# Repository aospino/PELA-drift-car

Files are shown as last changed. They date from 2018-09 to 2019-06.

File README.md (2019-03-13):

# PELA Drift Car
## 3D Printed LEGO-compatible 1:10 Scale RC Drift Car Cover

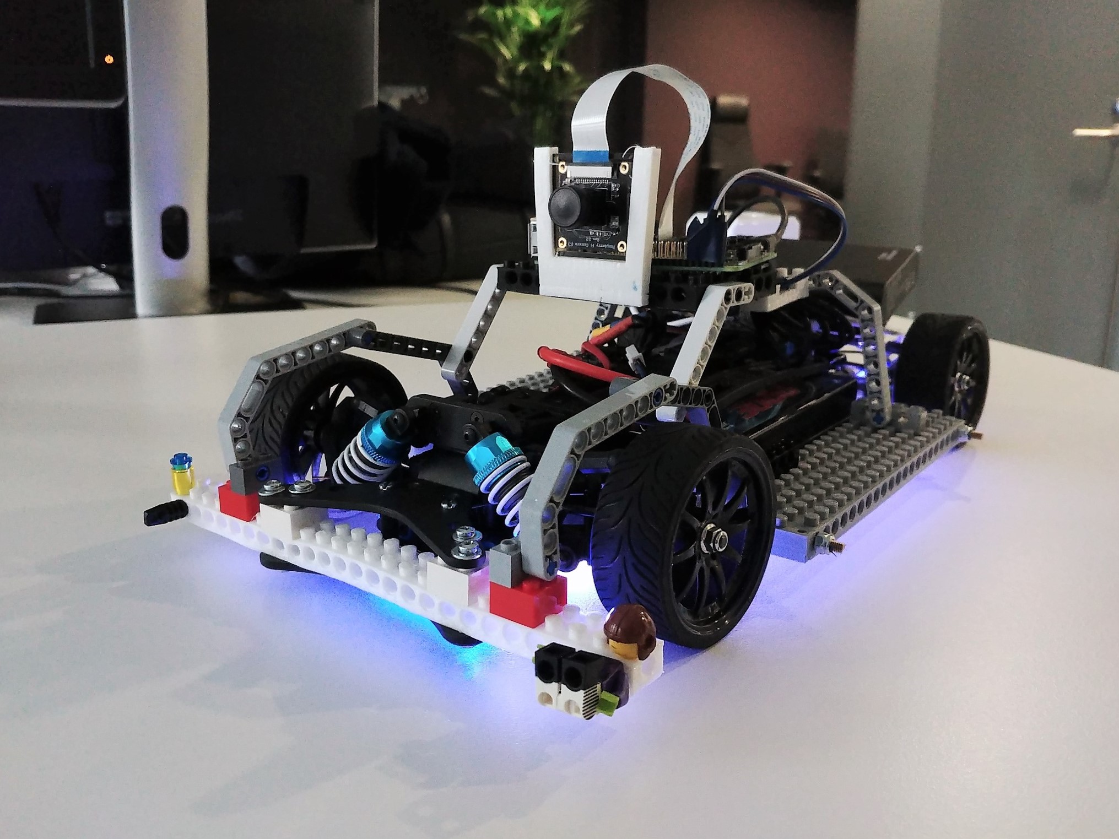
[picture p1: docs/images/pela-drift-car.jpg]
PELA Drift Car


`git clone git@github.com:LEGO-compatible-gadgets/PELA-drift-car.git --recurse-submodules`

Please visit the [GitHub Documentation](https://github.com/LEGO-compatible-gadgets/PELA-drift-car/tree/master/docs/README.md) for more information

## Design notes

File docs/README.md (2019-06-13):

# PELA Autonomous Drift Car
## 3D Printed LEGO-compatible Parametric 1:10 Scale RC Drift Car Cover Based On [PELA Blocks](http://pelablocks.org)

A high-end RC drift car is modified with 3D printed PELA blocks, LEGO technics, a Raspberry Pi 3+ and camera to drive itself. Snap on additional sensors and custom body parts as your design evolves. At Futurice, we use this to compete and learn. Our different offices race each other to see who has the mad deep learning skills to drive the car around a track the fastest.

To install, get the last preview release of [OpenSCAD](https://www.openscad.org/) then:

`git clone git@github.com:LEGO-compatible-gadgets/PELA-drift-car.git --recurse-submodules`

PELA Carson Drift Car

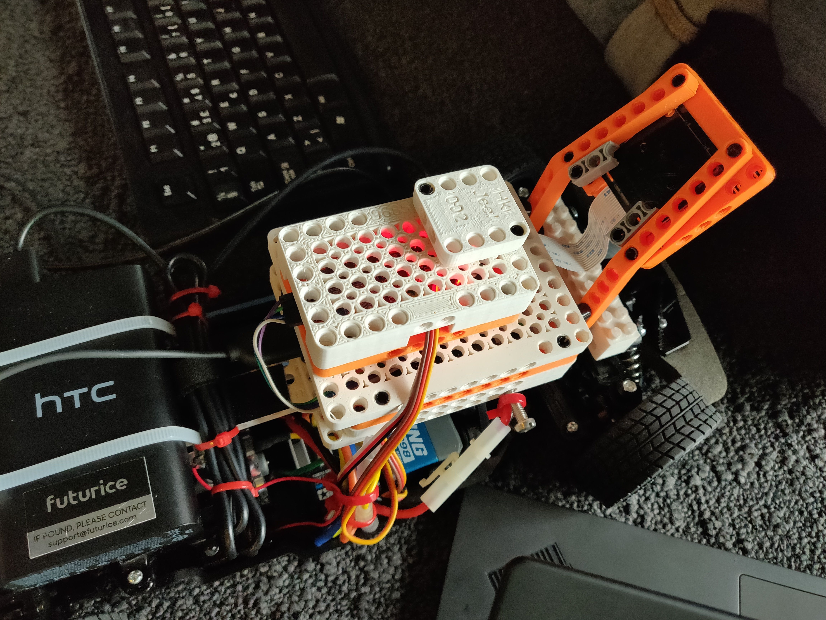
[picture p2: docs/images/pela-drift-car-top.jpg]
PELA TT-02 Drift Car


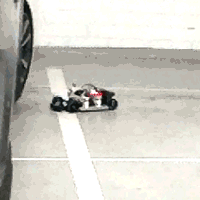
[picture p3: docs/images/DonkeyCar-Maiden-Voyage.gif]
PELA Drift Car Maiden Voyage




**This drift car is a work in progress.** PELA Blocks and some imagination with LEGO technics will offer you all the parts you need and see here in the picture. Instructions are currently a bit thin as we iterate fast. We'll get to it. Promise.

This car has been designed to compete in [Markku.ai](https://markku.ai/). You can find more resources and ideas there. **Markku.ai** is a **Donkeycar**-derived autonomous driving competition based using high end 1:10 electric drift cars. If you're going to crah- do it with style.

Please see [donkeycar.com](http://www.donkeycar.com/) for help with the basic software setup. This car is a high performace, pimped-out version of what you find there.

## Assembly Instructions

PELA Drift Car Assembly

[PELA Drift Car Assembly](https://github.com/LEGO-compatible-gadgets/PELA-drift-car/blob/master/PELA-drift-car-assembly.stl) Calibrate for your pinter as described in [PELA Blocks](https://pelablocks.org) and then export the calibrated models from [OpenSCAD](https://www.openscad.org/). Purchase a TT-02 car, boards, power bank battery and a bag of technic pins as needed. Aseemble according to the image and linked websites above. Drive. Win. 

## Models

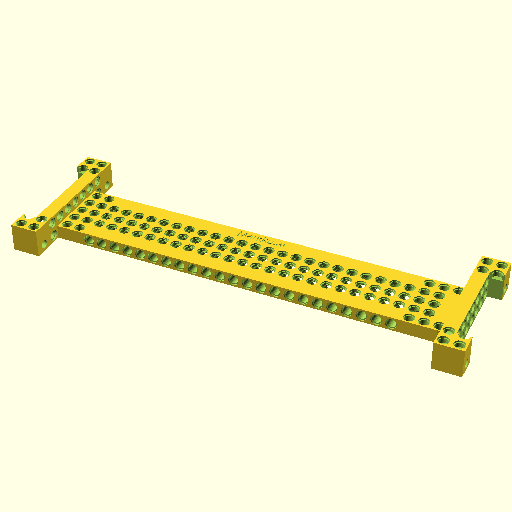
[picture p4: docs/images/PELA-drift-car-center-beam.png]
PELA Drift Car Center Beam


[PELA Drift Car Center Beam](https://github.com/LEGO-compatible-gadgets/PELA-drift-car/blob/master/PELA-drift-car-center-beam.stl) A configurable spine that runs down the center of an RC car for attaching other PELA parts. This part makes future upgrades and field reconfiguration and repair easier and much faster by using only technic pins are needed to make changes. For smaller printers, you may optionally render this as two shorter sections that can be joined by placing technic beams down the sides ovelapping both pieces. Use what you have laying around or print from [PELA technic beam](https://pelablocks.org).

___

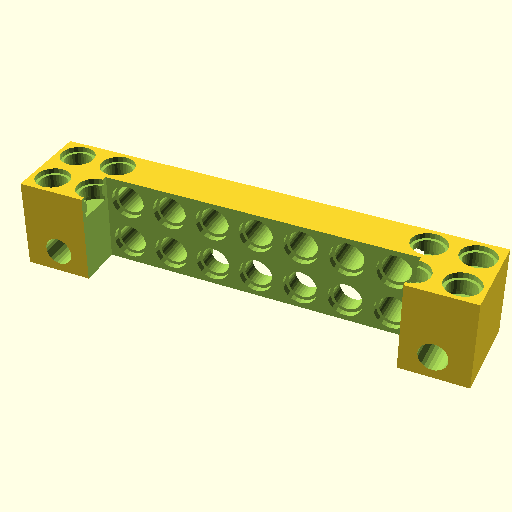
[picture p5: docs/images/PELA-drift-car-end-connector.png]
PELA Drift Car End Connector


[PELA Drift Car End Connector](https://github.com/LEGO-compatible-gadgets/PELA-drift-car/blob/master/PELA-drift-car-end-connector.stl) An adapter for both ends of the Drift Car Center Beam. Two mounting holes at each end allow quick disconnect of the entire electronics beam from the donor Tamiya TT-02 1:10 RC drift car. From the drop-down menu in OpenSCAD you can select an alternative design for a Carson drift car. The end connector holes line up with each car's mount holes. Use long technic pins or bolts to mount the end connector to the car near the suspension. The TT-02 model can be used for both front and back. The Carson connector only fits at the back of the car, so use a [strap mount](https://github.com/LEGO-compatible-gadgets/PELA-parametric-blocks/blob/master/PELA-strap-mount.stl) of appropriate size for the front attachment.

___

PELA Drift Car Tamiya TT-02 Body Mount

[PELA Drift Car Tamiya TT-02 Body Mount](https://github.com/LEGO-compatible-gadgets/PELA-drift-car/blob/master/PELA-body-mount.stl) An optional mounting point for a pre-made polycarbonate car body shell.

___

PELA Raspberry Pi 3B Technic Mount

[PELA Raspberry Pi 3B Technic Mount](https://github.com/LEGO-compatible-gadgets/PELA-parametric-blocks/blob/master/technic-mount/PELA-raspberry-pi3-technic-mount.stl) A Raspberry Pi 3B+ holder.

___

PELA PCA9685 16 Channel Servo Board Technic Mount

[PELA PCA9685 16 Channel Servo Board Technic Mount](https://github.com/LEGO-compatible-gadgets/PELA-parametric-blocks/blob/master/technic-mount/PELA-pca9685-servo-board-technic-mount.stl) For holding a servo driver board to the center bar.

___

PELA Raspberry Pi Camera Technic Mount

[PELA Raspberry Pi Camera Technic Mount](https://github.com/LEGO-compatible-gadgets/PELA-parametric-blocks/blob/master/technic-mount/PELA-raspberry-pi-camera-technic-mount.stl) A Raspberry Pi 3 camera holder.

___

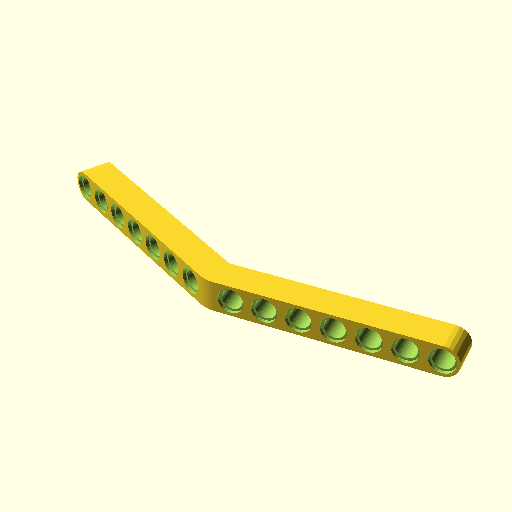
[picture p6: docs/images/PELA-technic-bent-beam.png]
PELA Technic Bent Beam


[PELA Technic Bent Beam](https://github.com/LEGO-compatible-gadgets/PELA-drift-car/blob/master/PELA-technic-bent-beam.stl) This is to mount the front wide angle Pi camera to the front TT-02 End Connector at a 30 degree down angle. Print two copies and make two small holes in the shell.

___

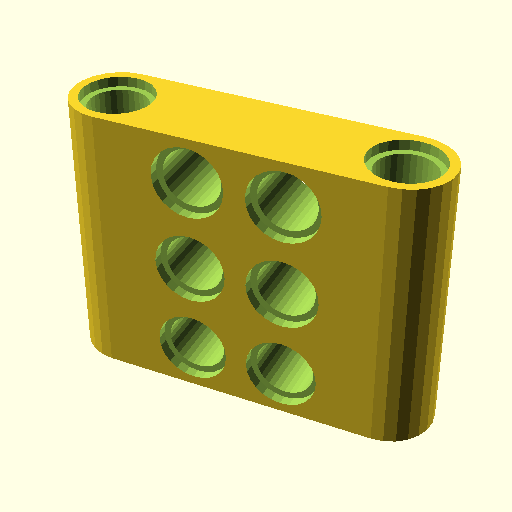
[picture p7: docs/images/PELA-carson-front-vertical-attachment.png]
PELA Vertical Attachment


[PELA Vertical Attachment](https://github.com/LEGO-compatible-gadgets/PELA-drift-car/blob/master/PELA-carson-front-vertical-attachment.stl) Two copies of this stick down from the front part of the center beam on a Carson to help with wire tie attachment to the center beam of the car.

___

PELA Technic Sign

[PELA Technic Sign](https://github.com/LEGO-compatible-gadgets/PELA-parametric-blocks/blob/master/sign/PELA-technic-sign.stl) A sign you can use to name and label your model.

## Downloading

If you prefer to avoid git, you can download the files instead.

1. Download and unzip **[PELA Drift Car](https://github.com/LEGO-Prototypes/PELA-drift-car/archive/master.zip)**
1. Download and unzip **[PELA Blocks](https://github.com/LEGO-Prototypes/PELA-blocks/archive/master.zip)** as a subdirectory inside the above (`PELA-robot-hand/PELA-blocks`)
1. **Calibrate** the models to your printer/filament/slicer/preferences (see below)

## Git Clone

1. `git clone git@github.com:LEGO-compatible-gadgets/PELA-drift-car.git --recurse-submodules`
1. **Calibrate** the models to your printer/filament/slicer/preferences (see below)
1. Before `git submodule update --remote` to get PELA Blocks project changes, you may want to [backup your print calibration files](http://pelablocks.org/#calibration-file-backup)

## Calibration

**IMPORTANT:** The STL models must be customized for your material, printer and slicer. First **[calibrate](http://pelablocks.org/#calibrate)** the PELA blocks for your printer to achieve a nice snap fit.

See also [Advanced Calibration](http://pelablocks.org/ADVANCED-CALIBRATION)

## Calibration File Backup

If you later update the PELA-blocks project to a newer version, you risk overwirting and loosing your calibration customizations. The simplest solution is to create a backup copy those settings.

1. `cd PELA-drift-car/PELA-Blocks`
1. `cp PELA-parameters.scad ../PELA-parameters-backup.scad`
1. `cp PELA-print-parameters.scad ../PELA-print-parameters-backup.scad`

## Use

Edit the [OpenSCAD](http://www.openscad.org/) files to generate different views such as one finger at a time.

Be patient, have a nice meal and a coffee, the models are complex and render slowly.

## License



**Creative Commons Attribution-ShareAlike 4.0 International License**

These designs are by PELA project contributors, not by the LEGO corporation. They are compatible with LEGO and similar blocks available from multiple manufacturers and online projects. The associated patents have expired. These designs are not identical to LEGO; they have been specially modified for easy 3D printing and offered in the spirit of open source collaborative innovation.

If what you want is available as injection molded plastic, buy it for the higher quality and durability. These model are helpful when you want something customized, a special color, an unusual material, and for replacement parts when you just can't wait.

## Open source design, Powered By Futurice

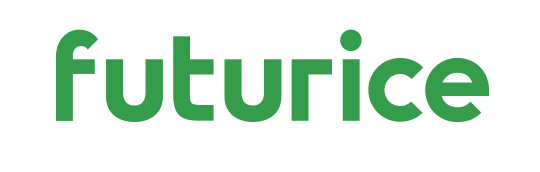
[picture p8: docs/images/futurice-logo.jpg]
Futurice (https://futurice.com)


These open source designs are brought to you by [Futurice](http://futurice.com) and contributions from the community. Come work with the best.

The software needed is free and open source, [OpenSCAD](http://www.openscad.org/). You can probably learn it in less than an hour.

## Contact

Collaboration and pull requests are welcome: [Git Project](https://github.com/LEGO-Prototypes/PELA-drift-car)

paul.houghton@futurice.com ( **[Blog](https://medium.com/@paulhoughton)** - **[Twitter](https://twitter.com/mobile_rat)** )

If you like it, please tweet about us! [](https://twitter.com/intent/tweet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)

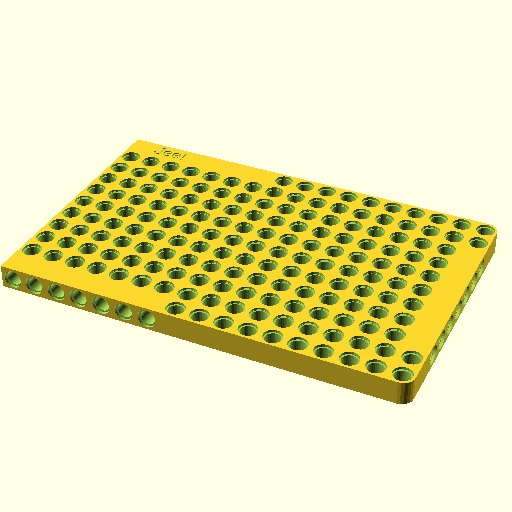
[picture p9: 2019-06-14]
docs/images/PELA-carson-center-beam.png

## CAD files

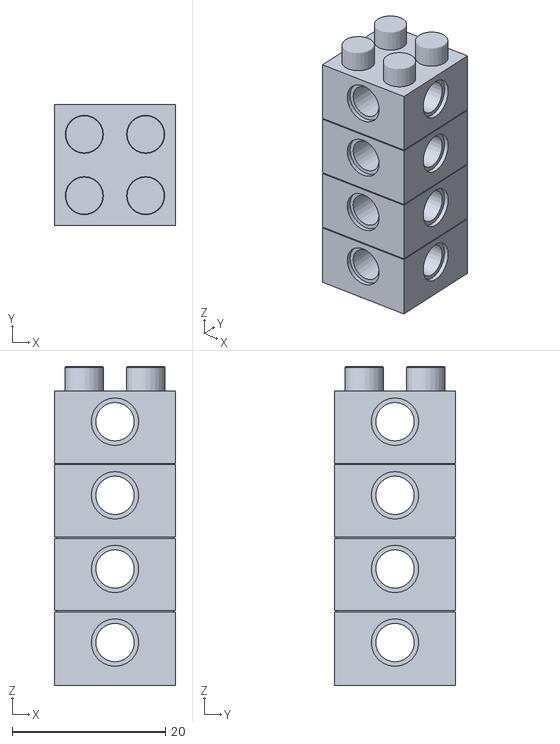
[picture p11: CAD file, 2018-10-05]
docs/riser-4-2-4.stl
15.8 x 15.8 x 41.6

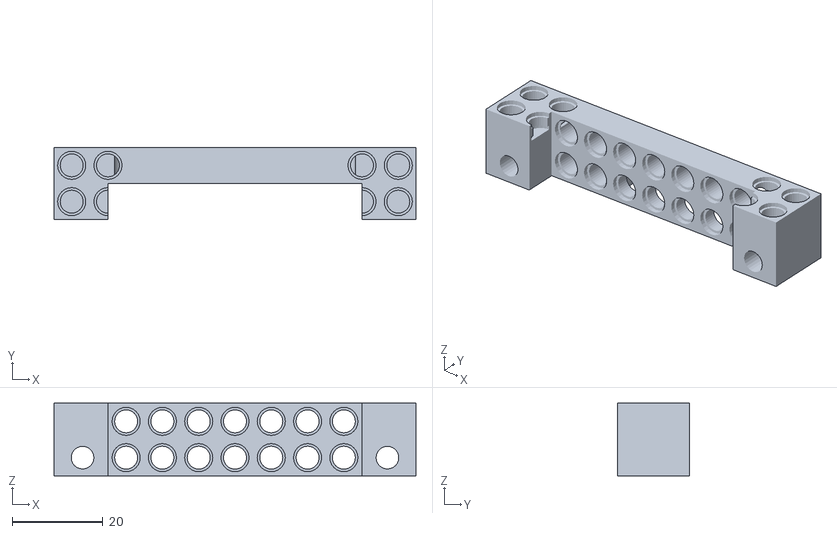
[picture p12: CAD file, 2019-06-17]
PELA-drift-car-end-connector.stl
79.8 x 15.8 x 16.0

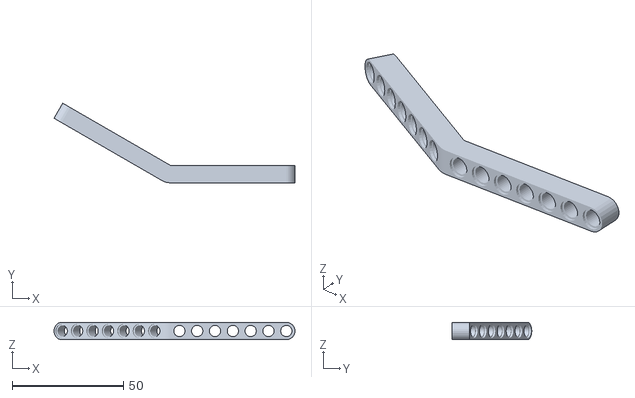
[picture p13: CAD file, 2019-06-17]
PELA-technic-bent-beam.stl
108.2 x 35.8 x 7.80

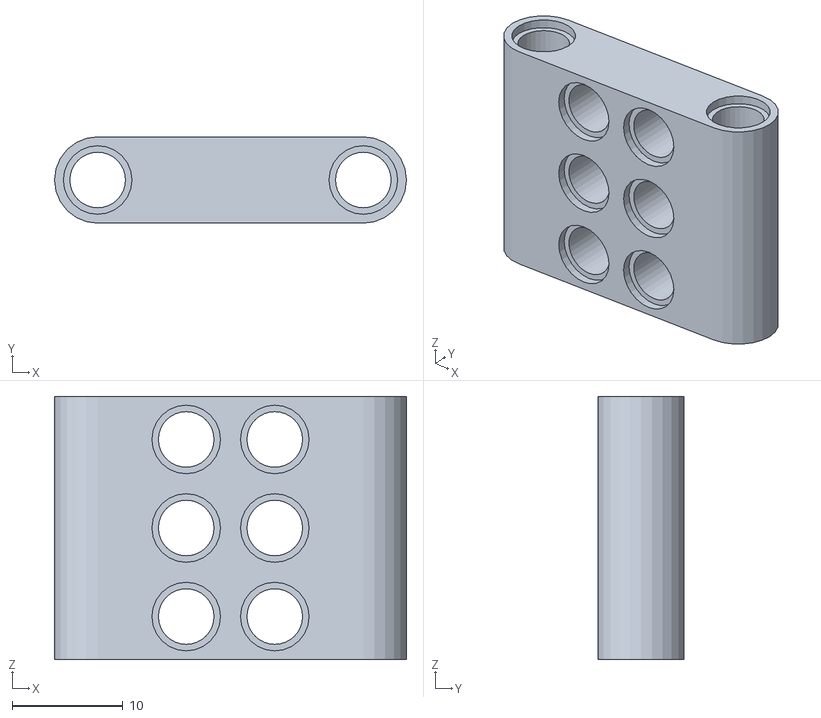
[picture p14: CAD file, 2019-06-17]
PELA-carson-front-vertical-attachment.stl
31.8 x 7.80 x 23.8

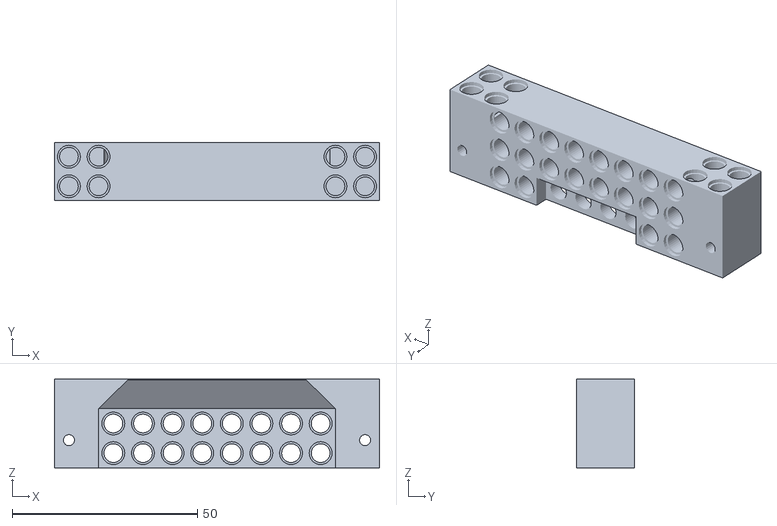
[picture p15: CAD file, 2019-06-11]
PELA-carson-drift-car-end-connector.stl
87.8 x 15.8 x 24.0

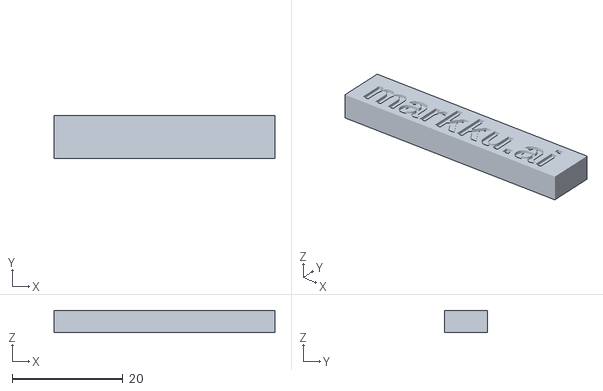
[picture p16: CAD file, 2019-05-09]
PELA-panel-sign.stl
39.8 x 7.82 x 4.00

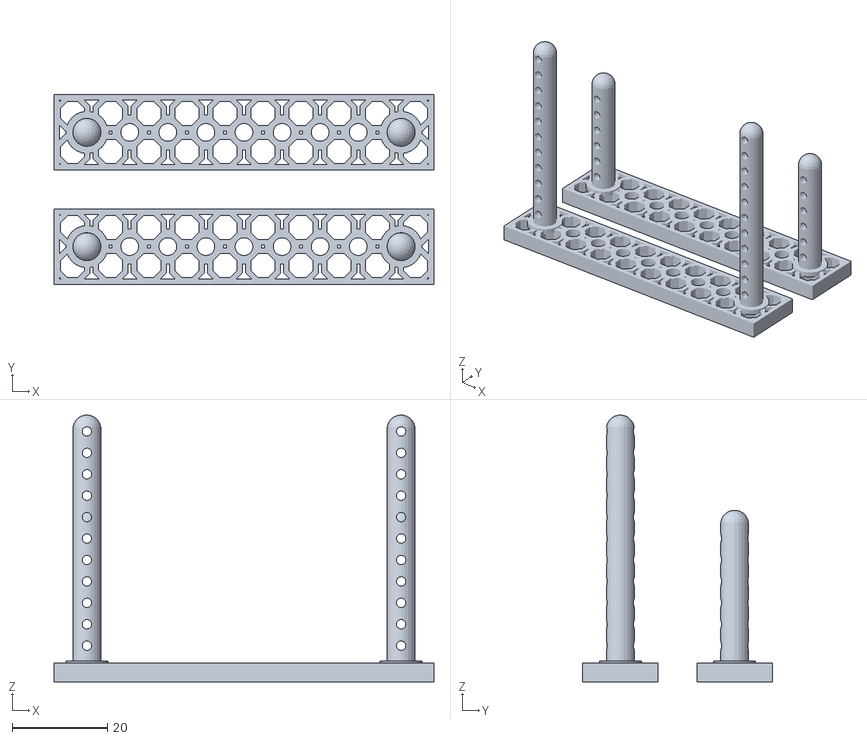
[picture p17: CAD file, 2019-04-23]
PELA-body-mount.stl
79.8 x 39.8 x 56.0

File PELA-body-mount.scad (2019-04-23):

/*
PELA Parametric Socket Panel Generator

Published at https://PELAblocks.org

By Paul Houghton
Twitter: @mobile_rat
Email: paulirotta@gmail.com
Blog: https://medium.com/@paulhoughton

Creative Commons Attribution-ShareAlike 4.0 International License
    https://creativecommons.org/licenses/by-sa/4.0/legalcode

Open source design, Powered By Futurice. Come work with the best.
    https://www.futurice.com/

Import this into other design files:
    use <PELA-block.scad>
*/

include <PELA-parametric-blocks/style.scad>
include <PELA-parametric-blocks/material.scad>
use <PELA-parametric-blocks/PELA-socket-panel.scad>



/* [Render] */

// Show the inside structure [mm]
cut_line = 0; // [0:1:100]

// Printing material (set to select calibrated knob, socket and axle hole fit)
material = 0; // [0:PLA, 1:ABS, 2:PET, 3:Biofila Silk, 4:Pro1, 5:NGEN, 6:NGEN FLEX, 7:Bridge Nylon, 8:TPU95, 9:TPU85/NinjaFlex]

// Is the printer nozzle >= 0.5mm? If so, some features are enlarged to make printing easier
large_nozzle = true;


/* [Body Mount] */

// Length of the socket panel [blocks]
l = 10; // [1:1:20]

// Width of the socket panel [blocks]
w = 4; // [1:1:20]

// Presence of sockets vs a plain panel
sockets = true;

// Add interior fill for the base layer
solid_first_layer = false;

// Basic unit vertical size of each block
block_height = 8; // [8:technic, 9.6:traditional blocks]


/* [Body Pins] */

// Space between the two front pin centers
pin_separation = 66.4; // [0:0.1:200]

// Thickness of the pin
pin_diameter = 5.8; // [0:0.1:20]

// Length of the pins
front_pin_height = 30.0; // [0:0.1:200]

// Length of the pins
back_pin_height = 50.0; // [0:0.1:200]

// Size of cotter pin holes in each pin
pin_hole_diameter = 2.0; // [0:0.1:20]

// Distance between cotter pin holes in each pin
pin_hole_spacing = 4.5; // [0:0.1:20]


///////////////////////////////
// DISPLAY
///////////////////////////////

front_body_mount();

translate([0, -block_width(w + 1), 0]) {
    back_body_mount();
}


module front_body_mount() {
    socket_panel(material=material, large_nozzle=large_nozzle, cut_line=cut_line, l=l, w=w, sockets=sockets, solid_first_layer=solid_first_layer, skin=skin, block_height=block_height);
    
    body_pin_set(pin_height=front_pin_height);
}

module back_body_mount() {
    socket_panel(material=material, large_nozzle=large_nozzle, cut_line=cut_line, l=l, w=w, sockets=sockets, solid_first_layer=solid_first_layer, skin=skin, block_height=block_height);
    
    body_pin_set(pin_height=back_pin_height);
}


module body_pin_set(pin_height = undef) {    
    translate([(block_width(l)-pin_separation)/2, 0, 0]) {
        body_pin(pin_height = pin_height);
    }
    
    translate([(block_width(l)+pin_separation)/2, 0, 0]) {
        body_pin(pin_height = pin_height);
    }
}

module body_pin(pin_height=undef) {
    assert(pin_height != undef);
    
    translate([0, block_width(w-1), knob_height+2*skin]) {
        difference() {
            union() {
                cylinder(d=pin_diameter, h=pin_height);
                translate([0, 0, pin_height]) {
                    sphere(d=pin_diameter);
                }
                cylinder(d=2*pin_diameter, h=panel_height());
            }

            for (i=[2*pin_hole_spacing:pin_hole_spacing:pin_height]) {
                translate([0, -pin_diameter, i]) {
                    rotate([-90, 0, 0]) {
                        cylinder(d=pin_hole_diameter, h=2*pin_diameter);
                    }
                }
            }
        }
    }
}

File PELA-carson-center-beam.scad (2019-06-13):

/*
PELA Slot Mount - 3D Printed LEGO-compatible PCB mount, vertical slide-in

Published at https://PELAblocks.org

By Paul Houghton
Twitter: @mobile_rat
Email: paulirotta@gmail.com
Blog: https://medium.com/@paulhoughton

Creative Commons Attribution ShareAlike NonCommercial License
    https://creativecommons.org/licenses/by-sa/4.0/legalcode

Design work kindly sponsored by
    https://www.futurice.com

All modules are setup for stateless functional-style reuse in other OpenSCAD files.
To this end, you can always pass in and override all parameters to create
a new effect. Doing this is not natural to OpenSCAD, so apologies for all
the boilerplate arguments which are passed in to each module or any errors
that may be hidden by the sensible default values. This is an evolving art.
*/

include <PELA-parametric-blocks/material.scad>
include <PELA-parametric-blocks/style.scad>
use <PELA-parametric-blocks/technic-beam/PELA-technic-beam.scad>
use <PELA-parametric-blocks/technic-mount/PELA-technic-box.scad>
use <PELA-parametric-blocks/PELA-technic-block.scad>



/* [Render] */

// Show the inside structure [mm]
_cut_line = 0; // [0:1:16]

// Printing material (set to select calibrated knob, socket and axle hole fit)
_material = 1; // [0:PLA, 1:ABS, 2:PET, 3:Biofila Silk, 4:Pro1, 5:NGEN, 6:NGEN FLEX, 7:Bridge Nylon, 8:TPU95, 9:TPU85/NinjaFlex]

// Is the printer nozzle >= 0.5mm? If so, some features are enlarged to make printing easier
_large_nozzle = true;

// Render front or back half of the beam
_front_half=true;


/* [Technic Beam] */

// Beam length [blocks]
_l = 15; // [1:1:30]

// Beam width [blocks]
_w = 1; // [1:1:30]

// Beam height [blocks]
_h = 1; // [1:1:30]

// Add full width through holes spaced along the length for techic connectors
_side_holes = 2; // [0:disabled, 1:short air vents, 2:full width connectors, 3:short connectors]



/* [Technic Beam] */

// Vertical clearance space between two parts to be placed next to one another on a 8mm grid [mm]
_vertical_skin = 0.1; // [0:0.02:0.5]

// Horizontal clearance space removed from the outer horizontal surface to allow two parts to be placed next to one another on a 8mm grid [mm]
_horizontal_skin = 0.1; // [0:0.02:0.5]



///////////////////////////////
// DISPLAY
///////////////////////////////
extra=36-18;

carson_l=_l+extra;
front_l=carson_l/2-0.5;

if (_front_half) {
    difference() {
        carson_beam();
        back_space(front_l=front_l);
    }
} else {
    intersection() {
        carson_beam();
        back_space(front_l=front_l);
    }
    
    translate([block_width(-1.5), block_width(-0.5), block_width(3)])
        rotate([0, 180, -90])
            end_connector();
}



///////////////////////////////////
// MODULES
///////////////////////////////////


module end_connector() {
    import("PELA-carson-drift-car-end-connector.stl", convexity=8);
}

module back_space(front_l) {
    translate([block_width(-0.5), block_width(-0.5), -block_width(1)])
        cube([block_width(front_l), block_width(11), block_width(10)]);
}


module carson_beam() {
    difference() {
        technic_box(material=_material, large_nozzle=_large_nozzle, cut_line=_cut_line, l=carson_l, w=11, h=1, twist_l=10, twist_w=2, knob_vent_radius=0, top_vents=0, center=3, text="Jee!      Jee!", text_depth=0.5, horizontal_skin=_horizontal_skin, vertical_skin=_vertical_skin, cover_corner_tabs=false, knob_height=0);

        union() {
            translate([block_width(10.5), block_width(4.5), -_defeather])
                cube([block_width(5), block_width(1), block_width(2)]);
        }
    }
}

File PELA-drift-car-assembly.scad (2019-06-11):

/*
PELA Technic Bent Beam - 3D Printed LEGO-compatible beam with an angle

Published at https://PELAblocks.org

By Paul Houghton
Twitter: @mobile_rat
Email: paulirotta@gmail.com
Blog: https://medium.com/@paulhoughton

Creative Commons Attribution ShareAlike NonCommercial License
    https://creativecommons.org/licenses/by-sa/4.0/legalcode

Design work kindly sponsored by
    https://www.futurice.com

All modules are setup for stateless functional-style reuse in other OpenSCAD files.
To this end, you can always pass in and override all parameters to create
a new effect. Doing this is not natural to OpenSCAD, so apologies for all
the boilerplate arguments which are passed in to each module or any errors
that may be hidden by the sensible default values. This is an evolving art.
*/

include <PELA-parametric-blocks/style.scad>
include <PELA-parametric-blocks/material.scad>
use <PELA-drift-car-center-beam.scad>
use <PELA-drift-car-end-connector.scad>
use <PELA-parametric-blocks/sign/PELA-technic-sign.scad>
use <PELA-parametric-blocks/technic-mount/PELA-pca9685-servo-board-technic-mount.scad>
use <PELA-parametric-blocks/technic-mount/PELA-raspberry-pi-camera-technic-mount.scad>
use <PELA-parametric-blocks/technic-mount/PELA-raspberry-pi3-technic-mount.scad>
use <PELA-parametric-blocks/pin/PELA-technic-pin.scad>
use <PELA-technic-bent-beam.scad>
use <PELA-body-mount.scad>


///////////////////////////////
// DISPLAY
///////////////////////////////
bw = block_width();
bh = block_height();

drift_car_center_beam();

translate([-0.5*bw, -bw, 7*bh])
    rotate([-90, 90, 0]) 
        drift_car_bent_beam();

translate([-0.5*bw, 5*bw, 7*bh])
    rotate([-90, 90, 0]) 
        drift_car_bent_beam();

translate([-2.5*bw, 7*bw, 0])
    rotate([0, 0, -90]) 
        drift_car_end_connector();

translate([30.5*bw, -3*bw, 0])
    rotate([0, 0, 90]) 
        drift_car_end_connector();

translate([-.755*bw, -bw, 7.438*bh])
    rotate([0, -120, 0]) {
        camera_mount();
    }

translate([-2.5*bw, 4*bw, 2*bh])
    rotate([0, 0, -90]) 
        technic_sign();

translate([-4.5*bw, 7*bw, 2*bh])
    rotate([0, 0, -90]) 
        front_body_mount();

translate([27.5*bw, 7*bw, 2*bh])
    rotate([0, 0, -90]) 
        back_body_mount();

translate([2.5*bw, -3*bw, 1*bh])
    rotate([0, 0, 0])
        union() {
            drift_car_pi_mount(render_modules=0);
            
            translate([0, 20*bw, 3*bh]) 
                rotate([180, 0, 0]) 
                    drift_car_pi_mount(render_modules=2);
            
            translate([0, -2*bw, 4*bh]) 
                rotate([180, 0, 0]) 
                    drift_car_pi_mount(render_modules=1);
        }
    
translate([22.5*bw, -3*bw, bh])
    rotate([0, 0, 90])
        union () {
            drift_car_9685_mount_and_cover(render_modules=0);
            
            translate([0, -2*bw, 3*bh])
                rotate([180, 0, 0])
                    drift_car_9685_mount_and_cover(render_modules=1);
        }

translate([32*bw, -2.3*bw, 0.5*bh])
    rotate([0, 90, 0])
        pin();

translate([32*bw, 6.3*bw, 0.5*bh])
    rotate([0, 90, 0])
        pin();

translate([-4*bw, -2.3*bw, 0.5*bh])
    rotate([0, 90, 0])
        pin();

translate([-4*bw, 6.3*bw, 0.5*bh])
    rotate([0, 90, 0])
        pin();

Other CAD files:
PELA-carson-front-vertical-attachment.scad
PELA-drift-car-center-beam.scad
PELA-drift-car-end-connector.scad
PELA-technic-bent-beam.scad
PELA-technic-sign.scad

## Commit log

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2018-08-25 Updated sculpting inside car body
    [PELA-driftcar-body.scad]
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2018-08-29 Rough Porsche 911 body
    [PELA-driftcar-body-negative.stl, PELA-driftcar-body.scad, PELA-knob-panel.stl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]
2018-08-29 Front and back now fit Taz6 bed
    [Porsche-driftcar-b-back.3mf, Porsche-driftcar-b-front.3mf, Porsche-driftcar-c-back.stl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]
2018-08-29 Try e, better shelling
    [Porsche-driftcar-d.3mf, Porsche-driftcar-e.3mf]
2018-08-31 First succesful print, NGEN, 1mm shell
    [PELA-knob-panel.stl, Porsche-driftcar-body-1mm.3mf, Porsche-driftcar-body-meshlab.stl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]
2018-08-31 Update to simple pela box holder for cor
    [PELA-driftcar-body.scad]
2018-09-03 Drift car board measures
    [drift-car-boards.scad]
2018-09-04 Iterate board holder wip
    [PELA-board-holder.scad, PELA-driftcar-body.scad]
2018-09-07 Board holder first print draft in ABS
    [PELA-board-holder.scad]
2018-09-07 Move Pi holder to subumodule
    [PELA-board-holder.scad]
2018-09-17 Add riser, update submodule
    [drift-car-boards.scad, riser.scad]
2018-09-19 Remove car models; update gitcleanup.ps1 to include 3mfcleanup
    [PELA-driftcar-body-negative.stl, PELA-knob-panel.stl, Porsche-driftcar-b.3mf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]
2018-09-21 Add bumper and body_mount template
    [PELA-drift-body_mount.scad, PELA-drift-car-bumper.scad]
2018-10-03 Update for slot mount and render
    [PELA-driftcar-body.scad]
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2018-10-05 Link fixes
    [PELA-driftcar-bumper.scad]
2018-10-08 First camera riser right only
    [camera-riser.scad]
2019-03-13 Adding markku.ai models for adaptation
    [bracket.stl, pin.stl]
2019-03-13 Upadates with basse models copied from submodule but locally built
    [PELA-driftcar-assembly.scad, PELA-driftcar-bumper.scad, PELA-pca9685-servo-knob-mount.scad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]
2019-03-13 Added center bar; rebuild
    [PELA-drift-car-center-bar.scad, PELA-pca9685-servo-knob-mount.stl]
2019-03-14 Wider and longer center bar
    [PELA-drift-car-center-bar.scad]
2019-03-15 Rebuild; added connector for TT-02
    [PELA-drift-car-tt02-end-connector.scad, PELA-drift-car-tt02-end-connector.stl, PELA-pca9685-servo-knob-mount.stl]
2019-03-18 Rebuild; end connector lower hole
    [PELA-drift-car-tt02-end-connector.scad, PELA-drift-car-tt02-end-connector.stl, PELA-pca9685-servo-knob-mount.scad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]
2019-03-18 Update submodule; rebuild; no difference
    [PELA-drift-car-tt02-end-connector.stl, PELA-pca9685-servo-knob-mount.stl]
2019-03-20 Update submodule; add dome parameter; dome the back of tt02-end-connector
    [PELA-drift-car-tt02-end-connector.scad, PELA-raspberry-pi3-camera-technic-mount.scad, PELA-raspberry-pi3-technic-mount.scad]
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2019-03-21 Update submodule; additional pi3camera params
    [PELA-raspberry-pi3-camera-technic-mount.scad]
2019-03-21 Pi3 technic mount fix
    [PELA-raspberry-pi3-technic-mount.scad]
2019-03-21 Submodule update; additional parameters based on pi3 model change
    [PELA-raspberry-pi3-technic-mount.scad]
2019-03-22 More down holes on the models vs standard form to allow easy attachment to the main bar; shorter main bar; drop down pre-configured ABS custom builds (JSON)
    [PELA-drift-car-center-bar.scad]
2019-04-01 Center bar can be printed in 2 parts
    [PELA-drift-car-center-bar.scad]
2019-04-01 More side holes on center bar, which can now be split and printed in two shorter pieces
    [PELA-drift-car-center-bar.scad]
2019-04-01 Better pi case; rebuild
    [PELA-drift-car-tt02-end-connector.stl, PELA-pca9685-servo-knob-mount.stl, PELA-raspberry-pi3-camera-technic-mount.scad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]
2019-04-02 Added addtional connector pieces with 2 options for mounting the front camera
    [PELA-drift-car-center-bar.scad, PELA-drift-car-tt02-end-connector.scad, PELA-raspberry-pi3-camera-technic-mount.scad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]
2019-04-02 Renaming files to line up webset
    [PELA-drift-car-center-beam.scad]
2019-04-09 Added servo board technic mount; removed servo board knob mount
    [PELA-pca9685-servo-board-technic-mount.scad]
2019-04-09 Fix tt02 end spacing; rebuild
    [PELA-drift-car-tt02-end-connector.scad, PELA-drift-car-tt02-end-connector.stl, PELA-pca9685-servo-knob-mount.scad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]
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2019-04-09 Remove center from cover of Pi camera
    [PELA-raspberry-pi3-camera-technic-mount.scad]
2019-04-10 Added full assembly; associated changes to support calling the different modules without warnings
    [PELA-drift-car-assembly.scad, PELA-drift-car-center-beam.scad, PELA-drift-car-tt02-end-connector.scad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]
2019-04-10 Remove obsolete Option B assembly (undesirably, confusing)
    [PELA-technic-angle-connector.scad, PELA-technic-angle-connector.stl, PELA-technic-block.scad]
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2019-04-11 Better hole spacing on end connector for TT-02
    [PELA-drift-car-tt02-end-connector.scad]
2019-04-18 Added socket panel for holding body pins
    [PELA-pca9685-servo-board-technic-mount.scad, PELA-socket-panel.scad]
2019-04-23 Added body mount- rebuild
    [PELA-body-mount.scad, PELA-body-mount.stl, PELA-drift-car-tt02-end-connector.stl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]
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2019-04-23 Added body mounts to assembly
    [PELA-drift-car-assembly.scad, PELA-drift-car-tt02-end-connector.scad, PELA-technic-bent-beam.scad]
2019-04-23 Extra holder for PCA board
    [PELA-pca9685-servo-board-technic-mount.scad]
2019-05-10 Center beam can include ends in a single print
    [PELA-drift-car-center-beam.scad, PELA-drift-car-tt02-end-connector.scad]
2019-05-16 Rebuild; added TT-02 image
    [PELA-drift-car-tt02-end-connector.stl, PELA-raspberry-pi3-camera-technic-mount.stl, PELA-technic-bent-beam.stl]
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2019-06-11 Link fix; rebuild
    [PELA-drift-car-assembly.scad, PELA-drift-car-end-connector.stl, PELA-technic-bent-beam.stl]
2019-06-11 Carson center beam back includes end connector WIP
    [PELA-carson-center-beam.scad, PELA-carson-drift-car-end-connector.stl]
2019-06-12 Removed gap in carson back w integrated mount
    [PELA-carson-center-beam.scad]
2019-06-13 Twist beam more options; Carson front beam fixup
    [PELA-carson-center-beam.scad, PELA-carson-front-vertical-attachment.scad]
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

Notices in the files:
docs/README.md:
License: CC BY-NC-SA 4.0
